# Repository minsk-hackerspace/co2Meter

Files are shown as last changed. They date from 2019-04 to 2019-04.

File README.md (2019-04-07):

# C02 Meter
ESP8266 + MZ-H19b + DHT11 + Oled1.3 = CO2 Meter

# Result
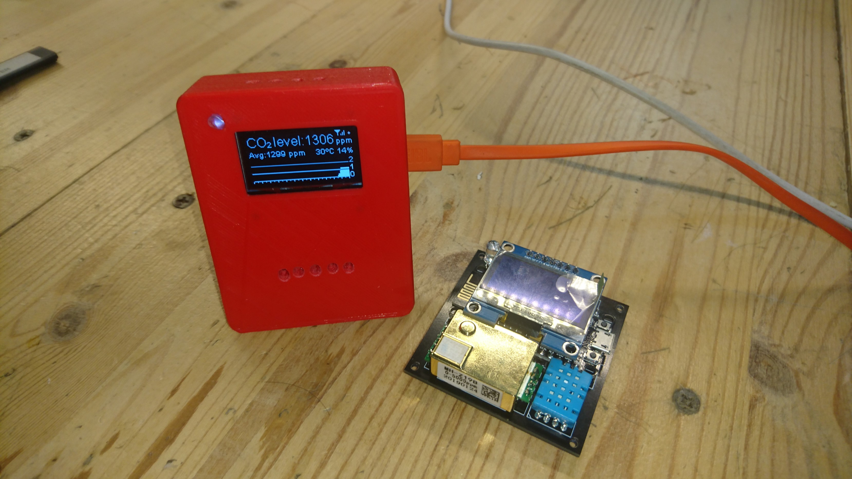
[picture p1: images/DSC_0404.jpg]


# Scheme
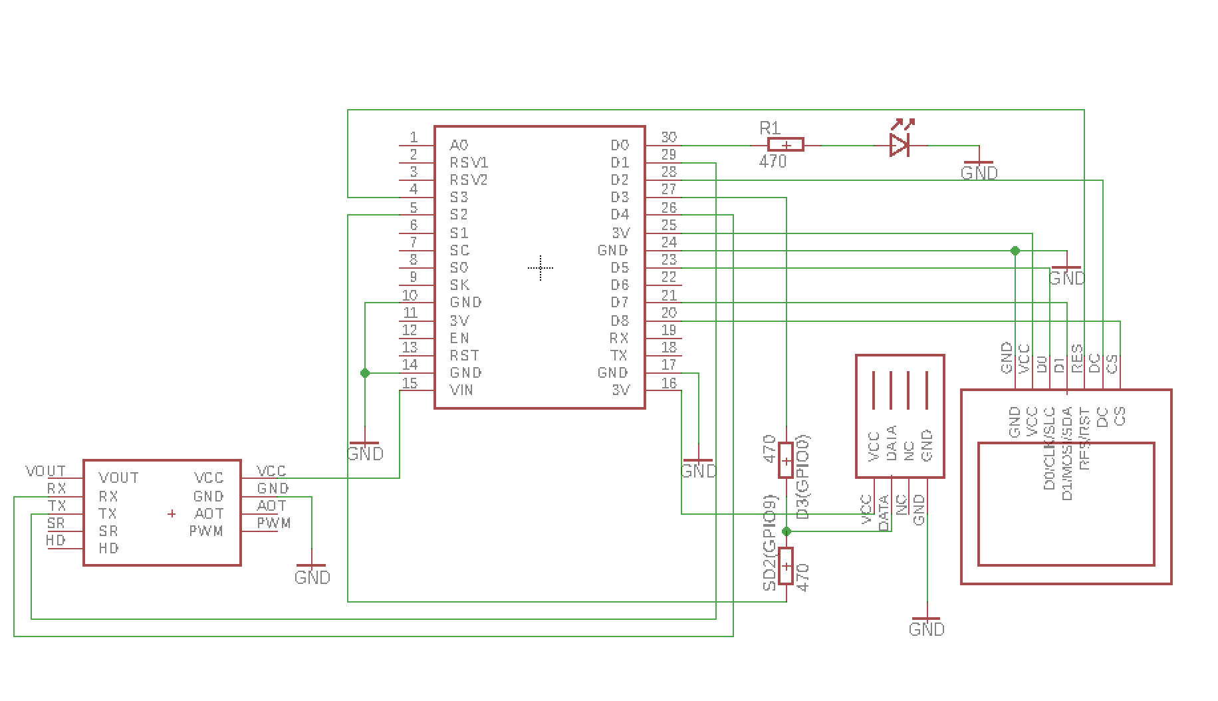
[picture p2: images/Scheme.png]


# ShopList:

- https://www.aliexpress.com/item/-/32860834286.html

- https://www.aliexpress.com/item/-/32802874451.html (cp2102)

- https://www.aliexpress.com/item/-/32844104782.html (1.3 White 7-pin SPI)

# Components
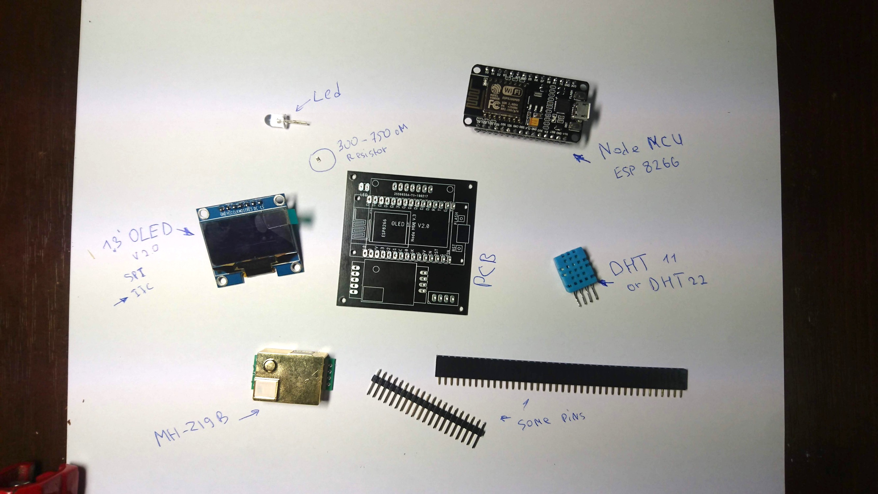
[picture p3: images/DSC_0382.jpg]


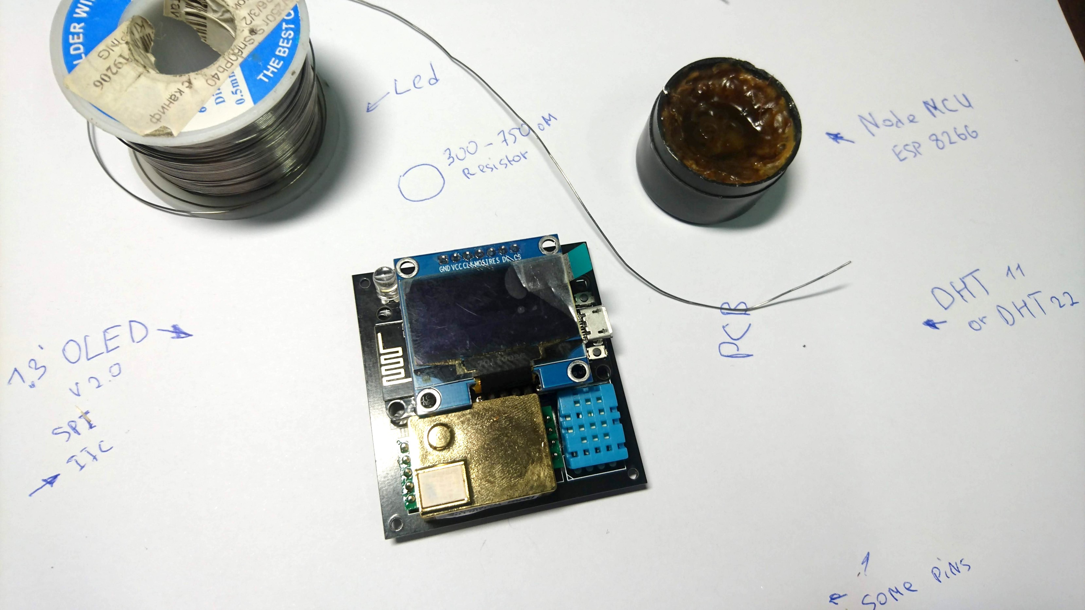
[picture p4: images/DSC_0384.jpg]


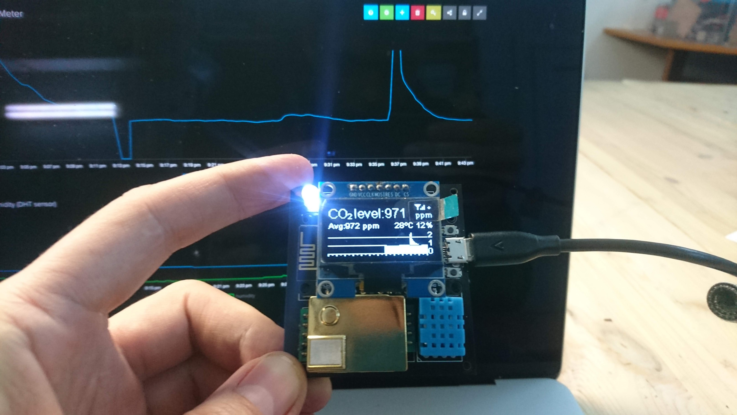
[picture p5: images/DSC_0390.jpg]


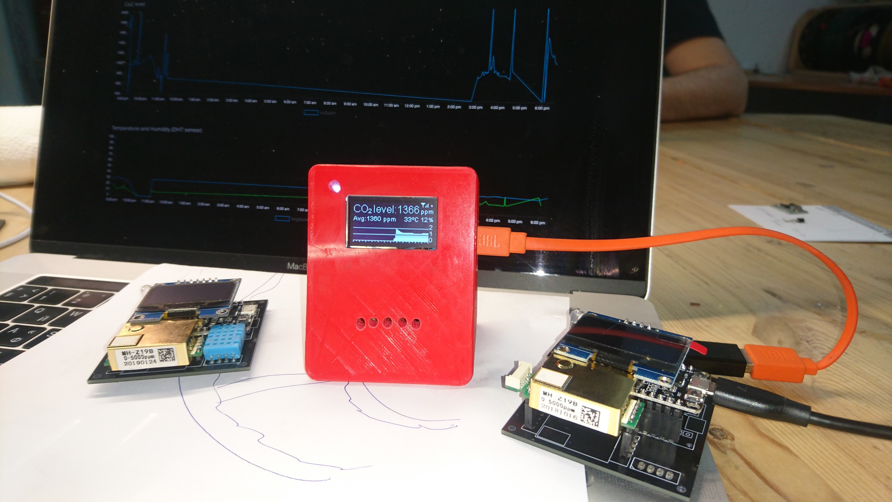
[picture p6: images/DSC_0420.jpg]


# Licensed under WTFPL

- http://www.wtfpl.net/

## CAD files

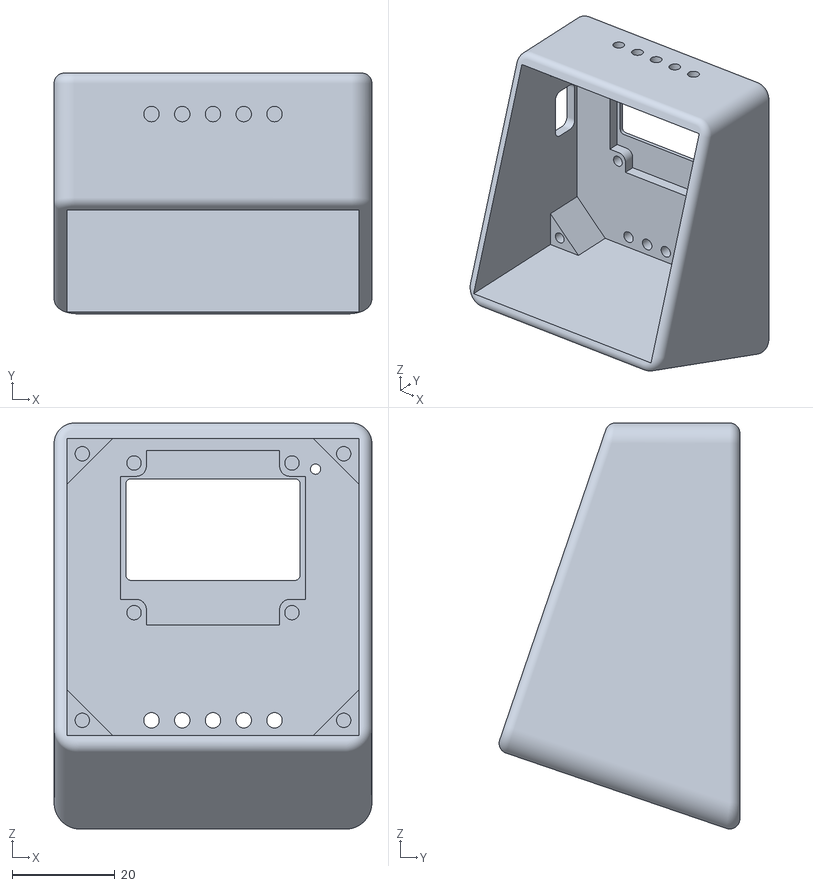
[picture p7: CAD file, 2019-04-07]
case/Case.stl
62.0 x 47.0 x 79.2

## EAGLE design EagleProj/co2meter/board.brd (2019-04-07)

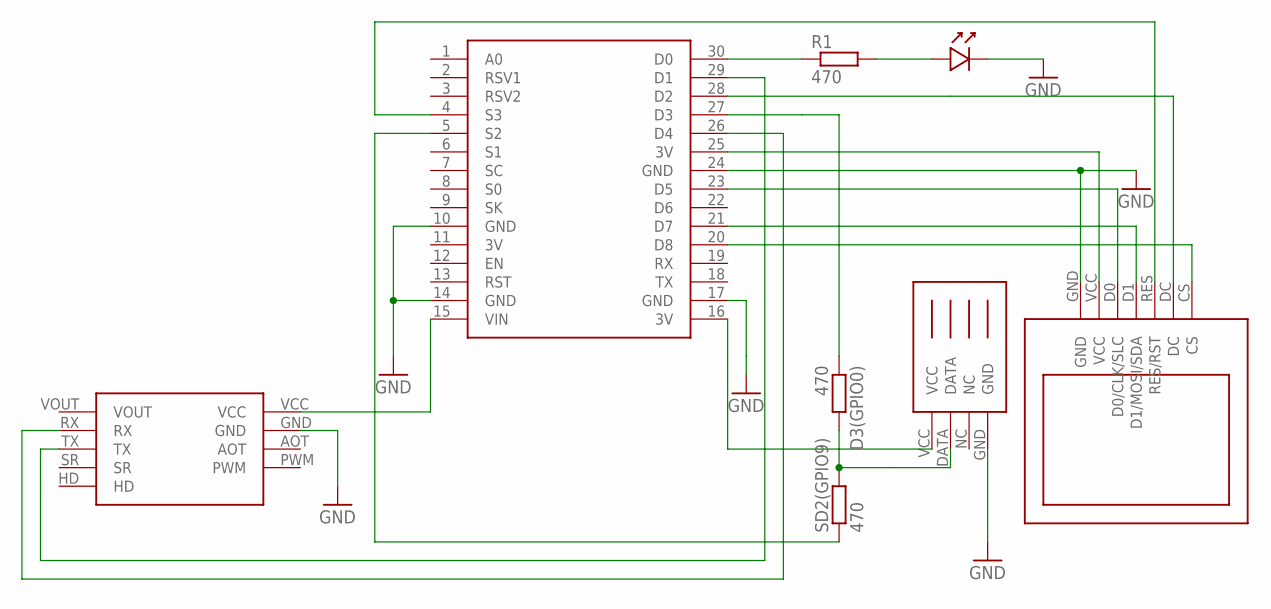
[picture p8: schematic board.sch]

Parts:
D3(GPIO0): 470; M1206
R1: 470; M1206
SD2(GPIO9): 470; M1206
U$1: NODEMCUV3; NODEMCU_V3
U$2: DHT11DEF; DHT11
U$3: MH_Z19BDEF; MH_Z19B
U$4: OLED_1.3_V2.0DEF; OLED_1.3_V2.0
U$6: LED_3MLED3M_3D; LEDRD254W60D300H500B

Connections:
3V: U$1.11 (3V)
GND: U$1.10 (GND), U$1.14 (GND), U$1.17 (GND), U$1.24 (GND), U$2.GND, U$3.GND, U$4.GND, U$6.2 (K)
unnamed: R1.1, U$1.30 (D0)
unnamed: D3(GPIO0).2, SD2(GPIO9).2, U$2.DATA
unnamed: U$1.4 (S3), U$4.RES (RES/RST)
unnamed: R1.2, U$6.1 (A)
unnamed: U$1.20 (D8), U$4.CS
unnamed: U$1.28 (D2), U$4.DC
unnamed: U$1.21 (D7), U$4.D1 (D1/MOSI/SDA)
unnamed: U$1.23 (D5), U$4.D0 (D0/CLK/SLC)
unnamed: U$1.15 (VIN), U$3.VCC
unnamed: U$1.26 (D4), U$3.RX
unnamed: U$1.29 (D1), U$3.TX
unnamed: U$1.16 (3V), U$2.VCC
unnamed: U$1.25 (3V), U$4.VCC
unnamed: SD2(GPIO9).1, U$1.5 (S2)
unnamed: D3(GPIO0).1, U$1.27 (D3)

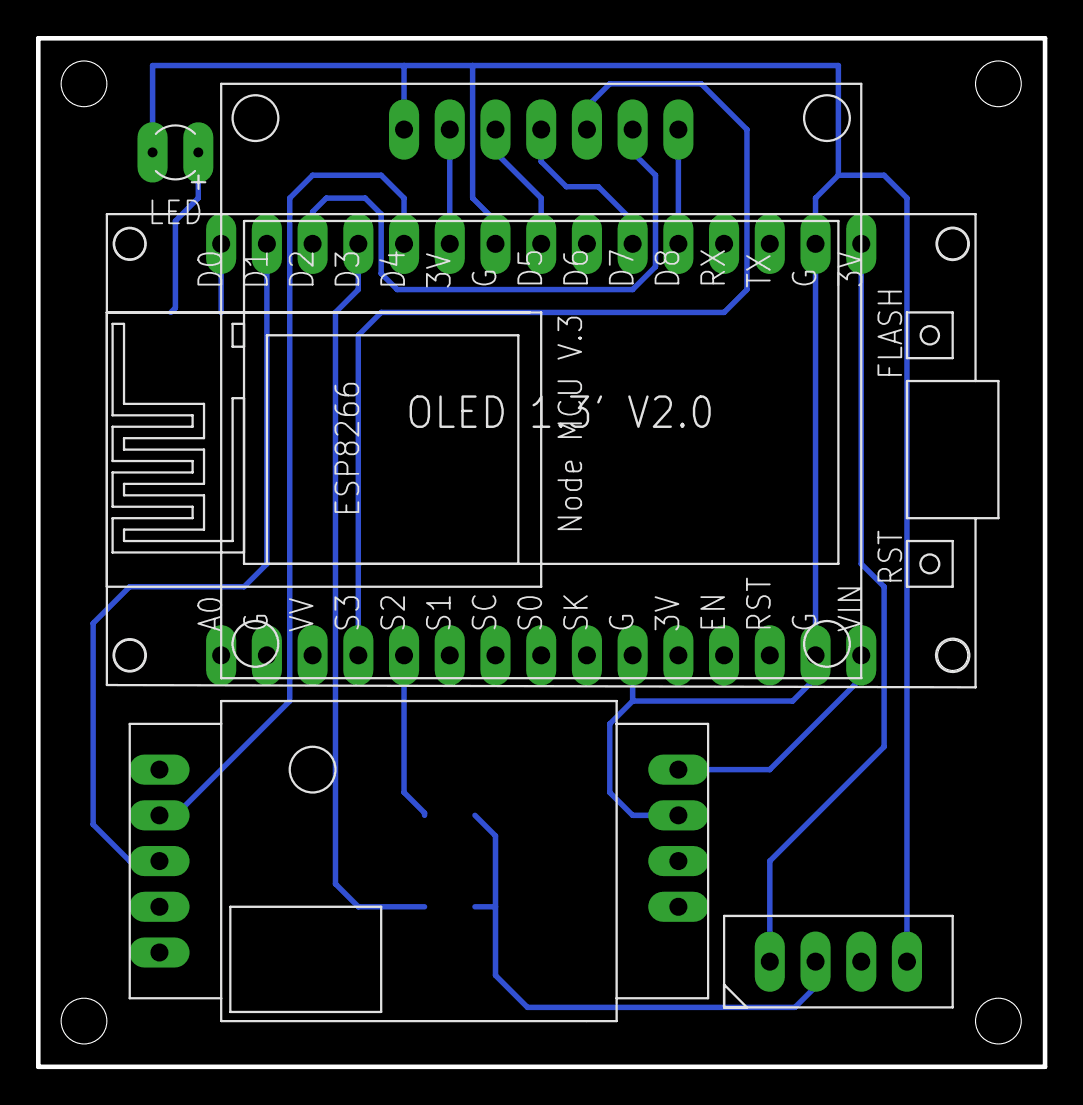
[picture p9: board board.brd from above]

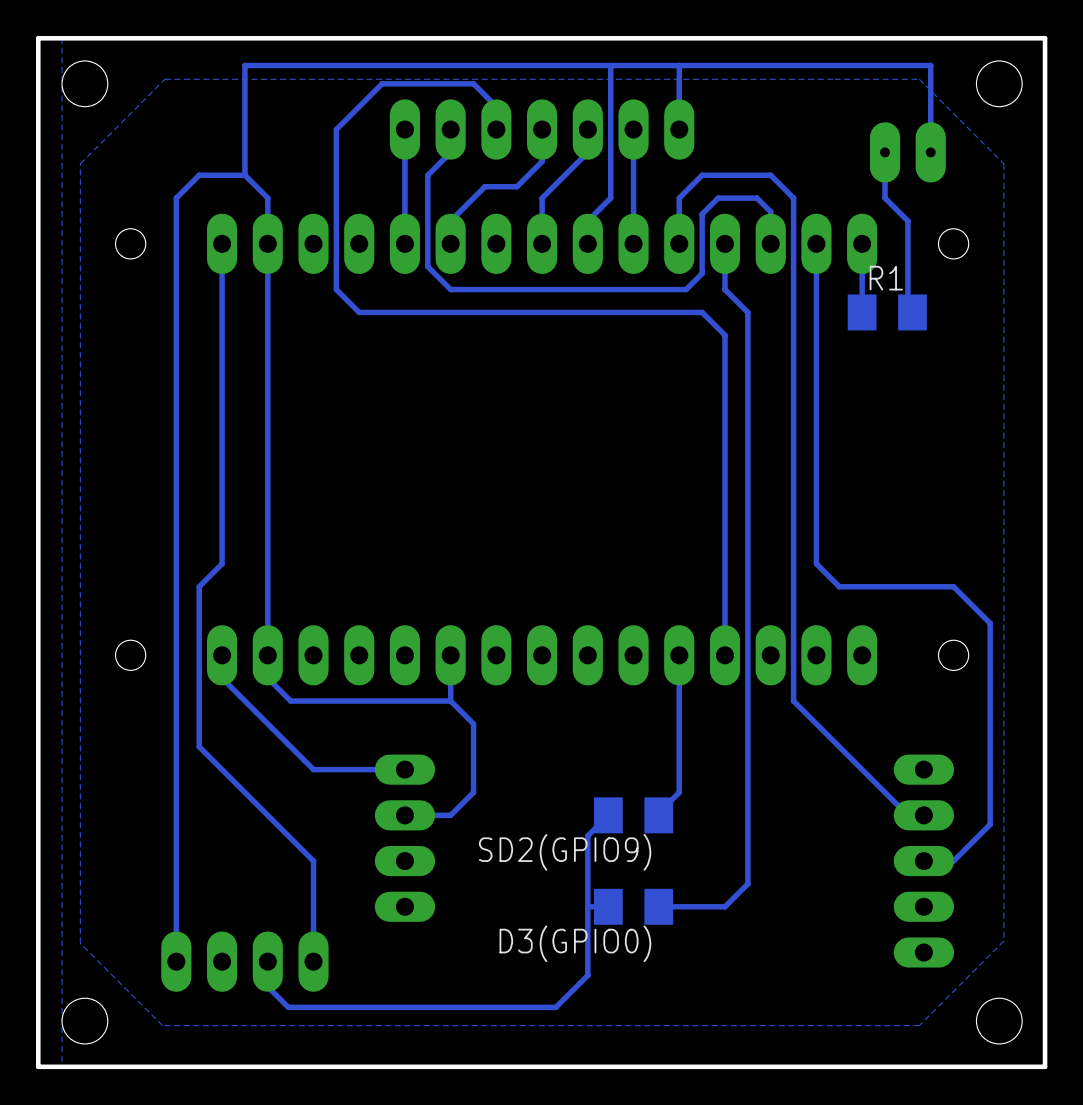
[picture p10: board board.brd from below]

Board: 2 copper layers, 55.9 x 57.1 mm, 8 parts (3 on the bottom side), 16 nets.

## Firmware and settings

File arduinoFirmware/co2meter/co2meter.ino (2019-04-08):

/*
 * TODO:
 * 
 * 
 * 
 * 
 * 
 * 
 * 
 */

extern "C" { //timer
#include "user_interface.h"
}


#include <ArduinoOTA.h> //https://github.com/esp8266/Arduino/tree/master/libraries/ArduinoOTA

#include <EEPROM.h> //Arduino lib for EEPROM
#include <FS.h> //https://github.com/esp8266/Arduino

#include <SoftwareSerial.h> //Arduino lib SoftwareUART for MH-Z19

#include <MHZ19.h>  //https://github.com/strange-v/MHZ19
#include <MHZ19PWM.h> //https://github.com/strange-v/MHZ19


#include <ArduinoJson.h> //https://github.com/bblanchon/ArduinoJson
#include <ESP8266WiFi.h> //https://github.com/esp8266/Arduino

#include <jled.h> //https://github.com/jandelgado/jled

#include <WiFiManager.h> //https://github.com/tzapu/WiFiManager
#include <DNSServer.h> //required for WiFiManager
#include <ESP8266WebServer.h> //required for WiFiManager

#include <PubSubClient.h> // https://github.com/knolleary/pubsubclient

//for DGT sensor
#include "DHTesp.h" //https://github.com/beegee-tokyo/DHTesp
DHTesp dht;

#define CONFIG_DISPLAY_SPI
//#define CONFIG_DISPLAY_I2C

// comment this for disable logging
#define DEBUG

#ifdef DEBUG
 #define DLG(x)  Serial.println(x); //Serial1.println(x);
#else
 #define DLG(x)
#endif

#define min(a,b) ((a)<(b)?(a):(b))

//const int LED_PIN = D0; //HADWARE LED
const int LED_PIN = LED_BUILTIN; //HADWARE LED PIN D0

const int HD_PIN = D3; //HARDWARE FLASH BTN
//const int DHT_PIN = D3; //SHARED wit hardware flash button
const int DHT_PIN = 9; //GPIO9 SDD2 SD2 Not available on some ESP (QIO mode)


const int SOFT_TX_PIN = D4; //tx 
const int SOFT_RX_PIN = D1; //rx

//for conecting with MH-Z19
SoftwareSerial mySerial(SOFT_RX_PIN, SOFT_TX_PIN);

MHZ19 mhz(&mySerial);

#ifdef CONFIG_DISPLAY_SPI
// SPI OLED display 128x64
#include <SPI.h>
#include "SH1106Spi.h"   // https://github.com/ThingPulse/esp8266-oled-ssd1306

//hadware SPI - to OLED pins
//const int OLED_CLK  = D5; //GPIO14 - CLK (D0)
//const int OLED_MISO = D6; //GPIO12 - not connected
//const int OLED_MOSI = D7; //GPIO13 - MOSI (D1)
const int OLED_CS     = D8; //GPIO15 - Chip select (CS)
const int OLED_DC     = D2; //GPIO4  - Data/Command (DC)
const int OLED_RESET  = 10; //GPIO10 SDD3 - RESET (RST)
SH1106Spi display(OLED_RESET, OLED_DC, OLED_CS); // FOR SPI
#endif

#ifdef CONFIG_DISPLAY_I2C
#include <Wire.h>
#include "SH1106Wire.h"   // https://github.com/ThingPulse/esp8266-oled-ssd1306

// I2C OLED display 128x64
#define OLED_ADDR   0x3C
const int OLED_SDA    = D7; //GPIO13 - SDA  (D1)
const int OLED_SDC    = D5; //GPIO14 - CLK (D0)
//hardware I2C - to OLED pins
SH1106Wire   display(OLED_ADDR, OLED_SDA, OLED_SDC);    // For I2C
#endif

int ppm = 0; //Текущее значение уровня СО2
int temp = 0; //Текущее значение температуры
int acc = 0; //Текущее значение точности

int dht_temp = 0; //last measured Temperature from DHT
int dht_hum = 0; //last measured Humidity from DHT

#define PPMS_L 120
int ppms[PPMS_L]= {};


int avg_ppm = 0; //average СО2 level for period measure_period
int avg_ppm_summ = 0; //measures summ
int avg_measures = 0; //measures count

unsigned int last_measured_time = 0; //last measure timestamp
unsigned int measured_time = 0; //measure time accumulator
const unsigned int measure_period = 1000*60*2; //2 minutes

const int measure_millis = 10000; //period between measurments in milliseconds


/*
 *
 * SATUS LED
 *
 */
JLed led = JLed(LED_PIN);//.LowActive();


/*
 *
 * Main Funcs
 *
 */
void reboot(void)
{
    led.Blink(10,50).Forever();
    DLG("Restarting...");
    delay(2000);
    ESP.restart();
}


/*
 *
 * OTA
 *
 */
bool OTA = false;

void setupOTA()
{

    DLG("Starting OTA");

    ArduinoOTA.setHostname("CO2 Meter OTA");
    ArduinoOTA.onStart([]() {
            Serial.println(" >> OTA onStart");
            });

    ArduinoOTA.onEnd([]() {
            Serial.println(" >> OTA onEnd");
            });

    ArduinoOTA.onError([](ota_error_t error) {
            Serial.println(" >> OTA onError");
            reboot();
            });

    led.Breathe(1000).Forever();
    OTA = true;
    /* setup the OTA server */
    ArduinoOTA.begin();

    DLG("OTA ready");

}

/*
 *
 * WiFiManager
 *
 */
void configModeCallback (WiFiManager *wifiManager)
{
    DLG("Entered config portal mode");
    led.Blink(400,100).Forever();

    display.clear();
    display.drawString(0, 0, "Could not connect to Wi-Fi");
    display.drawString(0, 10, "Starting access point...");
    display.display();
    String ip = String(WiFi.softAPIP().toString());
    String ap = wifiManager->getConfigPortalSSID();


    display.drawString(20, 24, "SSID:"+ap);
    display.drawString(20, 34, "IP:"+ip);
    display.display();

    DLG("AP:"+ap + " IP:" + ip);

}

WiFiClient espClient;

/*
 *
 * Config
 *
 */

bool shouldSaveConfig = false;
void saveConfigCallback ()
{
    DLG("Should save config");
    shouldSaveConfig = true;
}

String readConfigValue(int addr)
{
    String str = String();
    int address = addr;

    while(address < 512) {
        char c = char(EEPROM.read(address));
        if (c != 0 && c != 255) {
            str = str + c;
        } else {
            break;
        }
        address++;
    }
    return str;
}

void writeConfigValue(int addr, String str)
{
    for(int i=0; i<str.length(); i++) {
        EEPROM.write(addr+i,str[i]);
    }

    EEPROM.write(addr+str.length(),0);
    EEPROM.commit();
}


/*
 *
 * MQTT
 *
 */

char mqtt_server[40] = "io.adafruit.com";
const int ADDR_mqtt_server = 200;

char mqtt_port[6] = "1883";
const int ADDR_mqtt_port = 250;

char mqtt_user[40] = "user";
const int ADDR_mqtt_user = 300;

char mqtt_token[40] = "token_or_key";
const int ADDR_mqtt_token = 350;

char mqtt_topic[110] = "topic/feed/name/";
const int ADDR_mqtt_topic = 400;

PubSubClient mqtt(espClient);

void mqttCallback(char* topic, byte* payload, unsigned int length)
{
    DLG("MQTT : callback to " + String(topic) );
}

bool mqttConnect(int retries)
{

    if (WiFi.status() != WL_CONNECTED) {
        DLG("MQTT : Skip - No Wi-Fi");
        return false;
    }

    if (mqtt.connected()) {

        //DLG("MQTT : Connected");
        return true;

    } else {

        DLG("MQTT : Connect , WIFI : " + String(WiFi.status()) );

        led.Blink(20,200).Forever();

        String serv = String(mqtt_server);

        int port = strtol(mqtt_port, NULL, 10);

        mqtt.setCallback(mqttCallback);
        mqtt.setServer(serv.c_str(), port);

        DLG("MQTT : Connecting to :" + serv + ":" + String(port));

        int attempt = 0;

        while (!mqtt.connected() && attempt < retries ) {

            // Create a random client ID
            String clientId = "CO2_Meter_";
            clientId += String(random(0xffffff), HEX); 

            String username = String(mqtt_user);
            String key = String(mqtt_token);

            DLG("MQTT : Attempting connection using id:" + clientId + " username:" + username + " key:" + key);

            // Attempt to connect
            if (mqtt.connect(clientId.c_str() ,username.c_str() , key.c_str() ) ) {
                DLG("MQTT : Connected : " + String(mqtt.state()) + " with retry " + String(attempt) );
            } else {
                attempt++;
                DLG("MQTT : Not connected :"+ String(mqtt.state()) +" try to reconnect " + String(attempt) );
                delay(100);
            }
        }
    }

    return mqtt.connected();
}

void mqttPost(const char * stream, int value, int retries)
{

    if (mqttConnect(retries)) {
      String topic = String(mqtt_topic) + String(stream);
      String payload = String(value);
      bool ok = mqtt.publish(topic.c_str(), payload.c_str());

      DLG("MQTT : Publish "+ topic + " | " + payload + "  OK:" + String(ok));
    }
  }

/*
 *
 * Routine Timer
 *
 */
os_timer_t myTimer;

void timerCallback(void *pArg)
{
    led.Update();
}

void timerInit(void)
{
      os_timer_setfn(&myTimer, timerCallback, NULL);
      os_timer_arm(&myTimer, 20, true);
}


/*
 *
 * SETUP
 *
 */
void setup()
{
    Serial.begin(115200);
    analogWriteRange(255);
    timerInit();

    display.init();
    display.resetDisplay();
    //display.flipScreenVertically();
    display.clear();

    display.setFont(ArialMT_Plain_10);
    display.setTextAlignment(TEXT_ALIGN_LEFT);
    display.drawString(0, 0, "CO2 Meter initializing...");
    display.display();

    DLG("CO2: meter setup");
    pinMode(LED_BUILTIN, OUTPUT);

    led.On();
    pinMode(HD_PIN, INPUT_PULLUP);

    bool goConfig = false;  //will go config portal in case of Flash pressed in first 1.5 second
    for (int i=0; i<15; i++) {
        delay(100);
        if (digitalRead(HD_PIN)==LOW) {
            goConfig = true;
            DLG("Wifi will go to config portal");
            break;
        }
    }

    bool goOTA = true; //will start OTA in case of Flash pressed and hold for 3 sec
    led.Blink(10,500).Forever();
    for (int k=0; k<40; k++) {
        delay(100);
        if (digitalRead(HD_PIN)==HIGH) {
            goOTA = false;
            break;
        }
    }

    led.Off();

    if (goOTA) {
        led.On();
        goConfig = false;
        DLG("Wifi start OTA");
    }

    DLG("Read config");

    EEPROM.begin(512);

    String saved_mqtt_server = readConfigValue(ADDR_mqtt_server);
    String saved_mqtt_port = readConfigValue(ADDR_mqtt_port);
    String saved_mqtt_user = readConfigValue(ADDR_mqtt_user);
    String saved_mqtt_token = readConfigValue(ADDR_mqtt_token);
    String saved_mqtt_topic = readConfigValue(ADDR_mqtt_topic);

    DLG("MQTT : Serv:" + saved_mqtt_server + ":" + saved_mqtt_port
            + " username:" + saved_mqtt_user + " key:" + saved_mqtt_token + " topic:" + saved_mqtt_topic);

    if (saved_mqtt_server.length()) {
        strcpy(mqtt_server, saved_mqtt_server.c_str());
    }

    if (saved_mqtt_port.length()) {
        strcpy(mqtt_port, saved_mqtt_port.c_str());
    }

    if (saved_mqtt_user.length()) {
        strcpy(mqtt_user, saved_mqtt_user.c_str());
    }

    if (saved_mqtt_token.length()) {
        strcpy(mqtt_token, saved_mqtt_token.c_str());
    }

    if (saved_mqtt_topic.length()) {
        strcpy(mqtt_topic, saved_mqtt_topic.c_str());
    }


    //add wifimanager
    WiFiManager wifiManager;
    //add all your parameters here
    WiFiManagerParameter custom_mqtt_server("mqtt_server", "mqtt server", mqtt_server, 40);
    WiFiManagerParameter custom_mqtt_port("mqtt_port", "mqtt port", mqtt_port, 6);
    WiFiManagerParameter custom_mqtt_user("mqtt_user", "user", mqtt_user, 40);
    WiFiManagerParameter custom_mqtt_token("mqtt_token", "token_or_key", mqtt_token, 40);
    WiFiManagerParameter custom_mqtt_topic("mqtt_topic", "topic/feed/name/", mqtt_topic, 110);

    wifiManager.addParameter(&custom_mqtt_server);
    wifiManager.addParameter(&custom_mqtt_port);
    wifiManager.addParameter(&custom_mqtt_user);
    wifiManager.addParameter(&custom_mqtt_token);
    wifiManager.addParameter(&custom_mqtt_topic);

    wifiManager.setMinimumSignalQuality(10);
    wifiManager.setAPCallback(configModeCallback);
    wifiManager.setSaveConfigCallback(saveConfigCallback);
    wifiManager.setConfigPortalTimeout(60);

    led.Blink(10,100).Forever();

    if (goConfig) {
        DLG("Wifi reset and go config");
        //wifiManager.resetSettings();
        wifiManager.startConfigPortal("CO2 Meter");
    } else {
        DLG("Wifi auto connect");
        display.drawString(0, 10, "Connecting to Wi-Fi...");
        display.display();
        wifiManager.autoConnect("CO2 Meter");
    }


    //save Config Portal Settings
    //read updated parameters
    strcpy(mqtt_server, custom_mqtt_server.getValue());
    strcpy(mqtt_port, custom_mqtt_port.getValue());
    strcpy(mqtt_user, custom_mqtt_user.getValue());
    strcpy(mqtt_token, custom_mqtt_token.getValue());
    strcpy(mqtt_topic, custom_mqtt_topic.getValue());

    //save the custom parameters to FS
    if (shouldSaveConfig) {
        DLG("saving config");

        String new_mqtt_server = String(mqtt_server);
        String new_mqtt_port   = String(mqtt_port);
        String new_mqtt_user   = String(mqtt_user);
        String new_mqtt_token  = String(mqtt_token);
        String new_mqtt_topic  = String(mqtt_topic);

        if (new_mqtt_server.length()) {
            writeConfigValue(ADDR_mqtt_server, new_mqtt_server);
        }
        if (new_mqtt_port.length()) {
            writeConfigValue(ADDR_mqtt_port, new_mqtt_port);
        }
        if (new_mqtt_user.length()) {
            writeConfigValue(ADDR_mqtt_user, new_mqtt_user);
        }
        if (new_mqtt_token.length()) {
            writeConfigValue(ADDR_mqtt_token, new_mqtt_token);
        }
        if (new_mqtt_topic.length()) {
            writeConfigValue(ADDR_mqtt_topic, new_mqtt_topic);
        }

        //save
    }

    display.clear();
    display.display();
    DLG("Wifi Connected ? ");
    String msg = " + IP: " + WiFi.localIP().toString() + " ";
    DLG(msg);

    if(WiFi.status() == WL_CONNECTED) {

        DLG("Wifi Connected !");

        display.drawString(0, 0, "Wi-Fi conected");
        display.drawString(0, 10, msg);
        display.display();

        if (goOTA) {
            //starting OTA
            delay(100);
            display.drawString(0, 20, "Starting OTA ...");
            display.display();
            delay(500);
            setupOTA();
        } else {

            //connect MQTT
            delay(100);
            display.drawString(0, 20, "Connecting to MQTT server");
            display.display();
            delay(100);

            bool ok = mqttConnect(5);

            if (ok) {
                display.drawString(0, 30, " + connected");
            } else {
                display.drawString(0, 30, " - fail");
            }

            display.display();
            delay(1000);

        }


    } else {

        DLG("Wifi offline mode !");
        //offline mode
        WiFi.mode(WIFI_OFF);

        delay(100);
        display.drawString(0, 0, "Wi-Fi NOT Conected");
        display.display();
        delay(1000);
        display.drawString(0, 10, "Starting Offile mode");
        display.display();
        delay(100);
        display.drawString(0, 20, "     .      ");
        display.display();
        delay(100);
        display.drawString(0, 20, "     ..     ");
        display.display();
        delay(100);
        display.drawString(0, 20, "     ...    ");
        display.display();
        delay(100);

    }

    mySerial.begin(9600);
    dht.setup(DHT_PIN, DHTesp::DHT11);

    delay(1000);

    display.clear();
    display.display();

    // initial setup values

    memset(ppms, 0, PPMS_L);

    DLG("RUN !");

}


void displayDrawIcons()
{
    //anten
    display.fillRect(111, 0, 1, 7);
    display.fillRect(108, 0, 7, 1);
    display.fillRect(109, 1, 5, 1);
    display.fillRect(110, 2, 3, 1);

    if (WiFi.status() == WL_CONNECTED) { //connected wi-fi
        //palki
        display.fillRect(119, 1, 1, 6);
        display.fillRect(117, 3, 1, 4);
        display.fillRect(115, 5, 1, 2);

        if (mqtt.connected()) { //mqtt
            display.fillRect(124, 4, 3, 1);
            display.fillRect(125, 3, 1, 3);
        } else {
            display.fillRect(124, 4, 3, 1);
        }
    } else {
        display.setPixel(117, 4);
        display.setPixel(116, 5);
        display.setPixel(116, 3);
        display.setPixel(118, 5);
        display.setPixel(118, 3);

        display.setPixel(125, 4);
    }

}

void displayPrintData()
{
    String co2level = "CO  level:" + String(ppm) + " ";
    String co2levelAvg = "Avg:" + String(avg_ppm) + " ppm ";
    String templevel = "" + String(dht_temp) + "ºC " + String(dht_hum) + "%.";

    // draw on display
    display.setTextAlignment(TEXT_ALIGN_LEFT);

    display.setFont(ArialMT_Plain_16);
    display.drawString(0, 2, co2level);
    display.setFont(ArialMT_Plain_10);
    display.drawString(24, 8, "2");
    display.drawString(0, 20, co2levelAvg);
    display.setTextAlignment(TEXT_ALIGN_RIGHT);
    display.drawString(128, 20, templevel);
    display.drawString(128, 7, "ppm");
    display.drawString(128, 32, "2");
    display.drawString(128, 42, "1");
    display.drawString(128, 52, "0");

    //draw graph
    for (int x = 0; x <= 120; x++) {

        if (x%30 == 0) {
            display.setPixel(x, 63);
        }
        if (x%5 == 0) {
            display.setPixel(x, 62);
        }

    }

    display.fillRect(0, 61, 121, 1);
    display.fillRect(0, 51, 121, 1);
    display.fillRect(0, 41, 121, 1);

    display.setColor(INVERSE);
    for (int i = 0; i<PPMS_L ; i++) {
        unsigned int l_ppm = ppms[i];
        int y = (int)((int)l_ppm)/100;
        if (l_ppm != 0) {
            display.fillRect(120-i, 61-y, 1, y);
        } else {
            display.setPixel(0, 61);
        }
    }

}

void displayRefresh()
{

    display.clear();
    display.setColor(WHITE);

    displayDrawIcons();
    displayPrintData();

    display.display();

}

void measureDataMHZ()
{

    MHZ19_RESULT response = mhz.retrieveData();

    if (response == MHZ19_RESULT_OK) {
        ppm = mhz.getCO2();
        temp = mhz.getTemperature();
        acc = mhz.getAccuracy();
    } else {
        ppm = 0;
        temp = 0;
        acc = -1;
    }

    if (avg_ppm == 0 && ppm !=0) {
        avg_ppm = ppm;
    }


    avg_ppm_summ = avg_ppm_summ + ppm;
    avg_measures ++;

    String msg = ">> CO2 level:" + String(ppm) + " \t AVG:" + String(avg_ppm) + "\t temp:" + String(temp) +"\t acc:"+String(acc);
    DLG(msg);
}

void measureDataDHT()
{

    float humidity = dht.getHumidity();
    float temperature = dht.getTemperature();

    if (dht.getStatus() == 0) {

        dht_temp = (int) temperature;
        dht_hum = (int) humidity;
    }

    String msg = ">> DHT: " + String(dht.getStatusString()) + "\t temp:" + String(temperature) + "\t humn:" +  String(humidity);
    DLG(msg);

}


void postDataToMQTT()
{

    for (int i = 0 ; i<10 ; i++) {
        mqtt.loop();
        delay(5);
    }
    mqttPost("co2ppm", ppm, 3);

    for (int i = 0 ; i<10 ; i++) {
        mqtt.loop();
        delay(5);
    }
    mqttPost("co2temperature", temp, 0);

    for (int i = 0 ; i<10 ; i++) {
        mqtt.loop();
        delay(5);
    }
    mqttPost("co2accuracy", acc, 0);

    for (int i = 0 ; i<10 ; i++) {
        mqtt.loop();
        delay(5);
    }

    mqttPost("temperature", dht_temp, 0);

    for (int i = 0 ; i<10 ; i++) {
        mqtt.loop();
        delay(5);
    }

    mqttPost("humidity", dht_hum, 0);

    for (int i = 0 ; i<10 ; i++) {
        mqtt.loop();
        delay(5);
    }


}

// the loop function runs over and over again forever
void loop()
{

    //TODO : IRQ
    unsigned int before_loop_time = millis();

    if (OTA) {
        ArduinoOTA.handle();

        display.clear();
        display.setFont(ArialMT_Plain_10);
        display.setTextAlignment(TEXT_ALIGN_LEFT);
        display.drawString(10, 10, "CO2 Meter OTA...");
        String ip = " IP: " + WiFi.localIP().toString();
        display.drawString(10, 20, ip);
        display.display();

        return;
    }


    measureDataMHZ();
    measureDataDHT();

    displayRefresh();

    //status led
    int bval = 5000 - min(avg_ppm*2, 4400);
    led.Breathe(bval).Forever();

    postDataToMQTT();

    //time measure
    unsigned int cur_measure_time = millis();
    unsigned int measure_time_diff = 0;
    if (last_measured_time == 0 || cur_measure_time < last_measured_time) {
        measure_time_diff = measure_millis;//should be near this value
    } else {
        measure_time_diff = cur_measure_time - last_measured_time;
    }
    last_measured_time = cur_measure_time;
    measured_time = measured_time + measure_time_diff;

    if (measured_time > measure_period) {
        //DLG("period");
        measured_time = measured_time - measure_period;
        avg_ppm = avg_ppm_summ / avg_measures;
        //write avg to buffer;
        for (int i = PPMS_L-1 ; i>0 ; i--) {
            ppms[i] = ppms[i-1];
        }
        ppms[0] = avg_ppm;

        avg_ppm_summ = 0;
        avg_measures = 0;

    } else {

        unsigned int last_avg_ppm = ppms[0];
        if (last_avg_ppm) {
            avg_ppm = last_avg_ppm;
        } else {
            avg_ppm = avg_ppm_summ / avg_measures;
        }

    }


    //timings
    unsigned int diff = 0;
    unsigned int cur_loop_time = millis();

    if (cur_loop_time > before_loop_time) {
        // OK
        diff = cur_loop_time - before_loop_time;
    } else {
        //overflow what to do??? should be near to average measure time;
        diff = 1190; //average time for measurment
    }

    //DLG(millis());
    //DLG(diff);
    delay(measure_millis-diff);
    //DLG(millis());
}

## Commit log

2018-05-09 Update some status led
2019-04-07 Add DHT functions
    [Case.stl, board.brd, board.sch]
2019-04-07 Support an I2C interface for OLED display
